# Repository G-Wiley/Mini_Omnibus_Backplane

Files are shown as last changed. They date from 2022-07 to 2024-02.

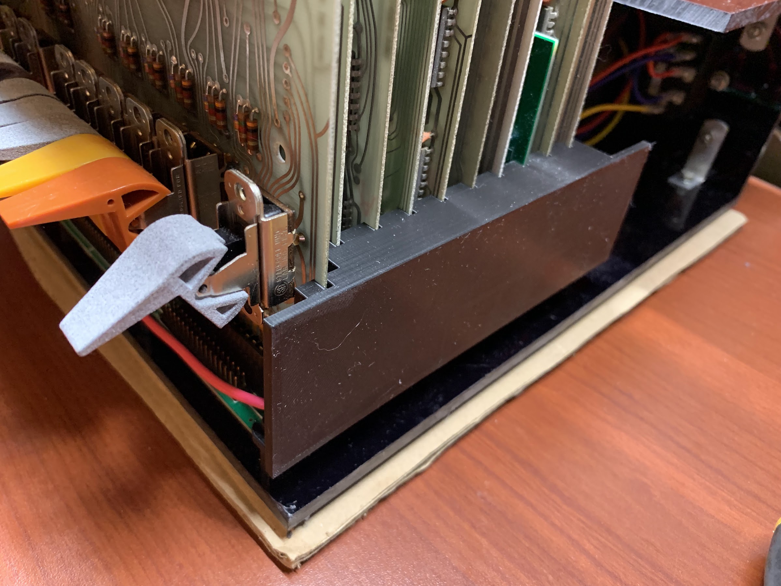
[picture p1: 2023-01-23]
Mini Backplane Card Guide photo.jpg

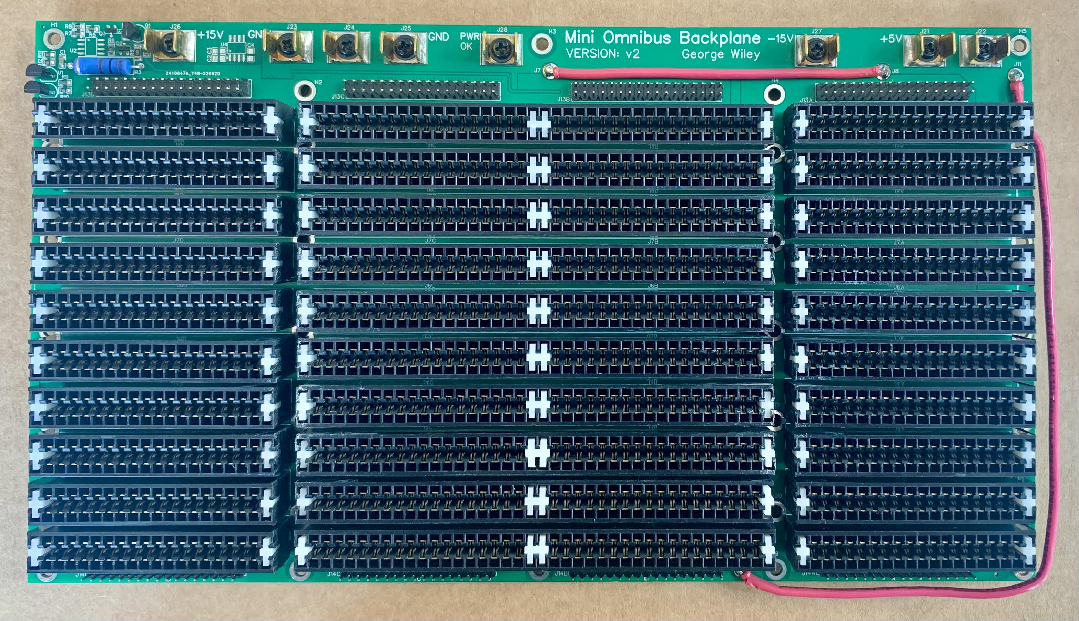
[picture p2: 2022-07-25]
Mini Omnibus Backplane v2 photo.jpg

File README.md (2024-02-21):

# Mini_Omnibus_Backplane
Small PDP-8/E/F/M Omnibus backplane for debugging Omnibus boards and to build a minimal system



For a long time I didn’t have a PDP-8/E/F/M chassis with backplane and power supply and wanted to get a system running using my Omnibus board collection. So, I built a small Omnibus backplane with only 8 slots which was sufficient to test basic stuff but not large enough to bring up OS/8. While debugging the first mini backplane I discovered some issues which have been fixed in version "v2". 

Through discussions in the Vintage Computer Forum and the PDP-8 group on Facebook there were a number of requests to release the design files of this mini backplane to use it for debugging and to build a system for those who do not have a real PDP-8 chassis+backplane+power supply. Included here are circuit board fabrication files, component source information and supplemental drawings and build documentation so people can build their own mini backplane.

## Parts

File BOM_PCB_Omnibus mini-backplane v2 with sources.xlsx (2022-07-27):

ID | Name | Designator | Footprint | Qty | Manufacturer Part | Manufacturer | Supplier | Supplier Part | Price | Ext Price | Supplier Link
1 | 1kΩ 1% | R10,R12 | R0805 | 2 | 0805W8F1001T5E | UNI-ROYAL(Uniroyal Elec) | LCSC | C17513 | 0.002 | 0.004 | https://jlcpcb.com/partdetail/18201-0805W8F1001T5E/C17513 | B
2 | 53.6Ω 1% | R11 | R0805 | 1 | 0805W8F536JT5E | UNI-ROYAL(Uniroyal Elec) | LCSC | C17744 | 0.003 | 0.003 | https://jlcpcb.com/partdetail/18432-0805W8F536JT5E/C17744 | E
3 | 2.0kΩ 1% | R9 | R0805 | 1 | 0805W8F2001T5E | UNI-ROYAL(Uniroyal Elec) | LCSC | C17604 | 0.003 | 0.003 | https://jlcpcb.com/partdetail/18292-0805W8F2001T5E/C17604 | B
4 | MC34164P-5G | U3,U1 | TO-92-3_L4.9-W3.7-P1.27-L | 2 | MC34164P-5G | ON Semi | Digikey | MC34164P-005GOS-ND | 0.88 | 1.76 | https://www.digikey.com/en/products/detail/onsemi/MC34164P-5G/919094
5 | 100nF | C1 | C0805 | 1 | CC0805KRX7R9BB104 | YAGEO | LCSC | C49678 | 0.004 | 0.004 | https://jlcpcb.com/partdetail/Yageo-CC0805KRX7R9BB104/C49678 | B
6 | 47kΩ | R7,R5 | R0805 | 2 | 0805W8F4702T5E | UNI-ROYAL(Uniroyal Elec) | LCSC | C17713 | 0.002 | 0.004 | https://jlcpcb.com/partdetail/18401-0805W8F4702T5E/C17713 | B
7 | 470kΩ | R8 | R0805 | 1 | 0805W8F4703T5E | UNI-ROYAL(Uniroyal Elec) | LCSC | C17709 | 0.004 | 0.004 | https://jlcpcb.com/partdetail/18397-0805W8F4703T5E/C17709 | B
8 | 100Ω | R3 | RES-TH_BD5.0-L15.5-P19.50-D0.70 | 1 | RSF2JT100R | Stackpole Electronics Inc | Digikey | RSF2JT100RTR-ND | 0.34 | 0.34 | https://www.digikey.com/en/products/detail/stackpole-electronics-inc/RSF2JT100R/1686318
9 | MMBT3904 | Q2 | SOT-23-3_L2.9-W1.3-P1.90-LS2.4-BR | 1 | MMBT3904 | Jiangsu Changjing Electronics Technology Co., Ltd. | LCSC | C20526 | 0.014 | 0.014 | https://jlcpcb.com/partdetail/21237-MMBT3904/C20526
10 | MMBT3906 | Q3 | SOT-23-3_L2.9-W1.3-P1.90-LS2.4-BR | 1 | MMBT3906 | ST(Semtech) | LCSC | C84105 | 0.01 | 0.01 | https://jlcpcb.com/partdetail/st_semtech-MMBT3906/C84105
11 | 100Ω | R1,R2 | R1206 | 2 | 1206W4F1000T5E | UNI-ROYAL(Uniroyal Elec) | LCSC | C17901 | 0.004 | 0.008 | https://jlcpcb.com/partdetail/18589-1206W4F1000T5E/C17901 | B
12 | 0Ω | R4 | R0805 | 1 | 0805W8F0000T5E | UNI-ROYAL(Uniroyal Elec) | LCSC | C17477 | 0.002 | 0.002 | https://jlcpcb.com/partdetail/18165-0805W8F0000T5E/C17477 | B
13 | 1.5kΩ | R6 | R0805 | 1 | 0805W8F1501T5E | UNI-ROYAL(Uniroyal Elec) | LCSC | C4310 | 0.002 | 0.002 | https://jlcpcb.com/partdetail/4717-0805W8F1501T5E/C4310 | B
14 | Keystone 1257 Quick-Fit | J21, J22, J23, J24, J25, J26, J27, J28 | KEYSTONE_1257_FP | 8 | 1257 | Keystone Electronics | Digikey | 36-1257-ND | 0.27 | 2.16 | https://www.digikey.com/en/products/detail/keystone-electronics/1257/211498
15 | X6521WR-2×17H-C30D60-gw-NSP | J14A, J14B, J14C, J14D, J13A, J13B, J13C, J13D | HDR-TH_34P-P2.54-H-M-R2-C17-S2.54-NO-SILK-PINS | 8 | PRPC017DAAN-RC | Sullins Connector Solutions | Digikey | S2011EC-17-ND | 0.671 | 5.368 | https://www.digikey.com/en/products/detail/sullins-connector-solutions/PRPC017DAAN-RC/2775277
16 | Omnibus | J1B-J1C, J2B-J2C, J3B-J3C, J4B-J4C, J5B-J5C, J6B-J6C, J7B-J7C, J8B-J8C, J9B-J9C, J10B-J10C | OMNIBUS CARD EDGE SOCKET | 10 | n/a | n/a | AliExpress alinsin store | 1PCS 2X40 80PIN | 2.91 | 29.1 | https://www.aliexpress.com/item/2255801094078491.html
16 | Omnibus | J1A & J1D, J2A & J2D, J3A & J3D, J4A & J4D, J5A & J5D, J6A & J6D, J7A & J7D, J8A & J8D, J9A & J9D, J10A & J10D | OMNIBUS CARD EDGE SOCKET | 10 | n/a | n/a | AliExpress alinsin store | 1PCS 2X43 86PIN | 3.1 | 31 | https://www.aliexpress.com/item/2255801094078491.html
17 | 2N3904BU | Q1 | TO-92-3_L5.1-W4.1-P1.27-L | 1 | 2N3904BU | ON Semi | Digikey | 2N3904FS-ND | 0.38 | 0.38 | https://www.digikey.com/en/products/detail/onsemi/2N3904BU/1413
 | PCB, Mini Backplane v2 | - | - | 1 |  | JLCPCB | JLCPCB |  |  |  | https://jlcpcb.com/
 | cap screw, M3, 8 mm | H1 - H30 | - | 30 |  |  | Amazon |  |  |  | https://www.amazon.com/dp/B07CMQ1SQH
 | cap screw, M3, 12 mm | - | - | 30 |  |  | Amazon |  |  |  | https://www.amazon.com/dp/B07CNFTK99
 | M3 split lock washer | - | - | 60 |  |  | Amazon |  |  |  | https://www.amazon.com/dp/B07Z2FJ2XW
 | M3 flat washer | - | - | 30 |  |  | Amazon |  |  |  | https://www.amazon.com/dp/B018TG7QGW
 | pan head screw, M3, 4 mm | - | - | 8 |  |  | Amazon |  |  |  | https://www.amazon.com/dp/B0748BR25Y
 | nut, M3, black | - | - | 8 |  |  | Amazon |  |  |  | https://www.amazon.com/dp/B01IWUSDYY
 | nylon spacer, threaded, M3 | - | - | 12 |  |  | Amazon |  |  |  | https://www.amazon.com/dp/B072LGMRVD
 | acrylic sheet, 1/4 inch | - | - | 1 | n/a | various | ePlastics | scrap |  |  | n/a

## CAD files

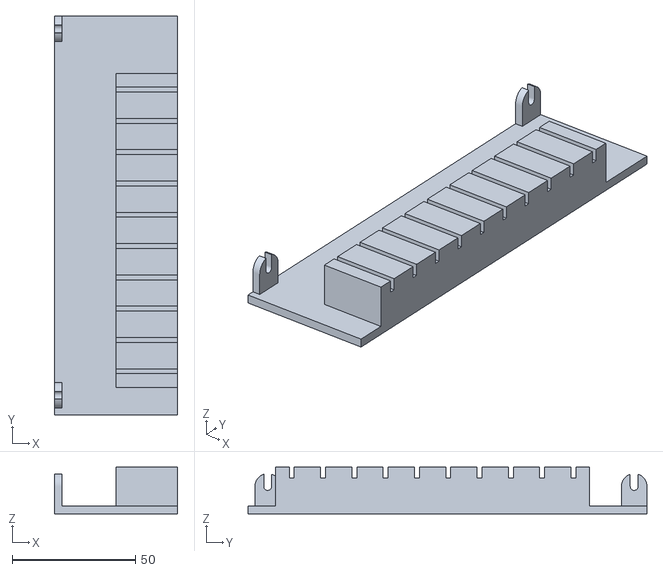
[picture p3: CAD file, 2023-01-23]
Mini Backplane Card Guide 10 same v00.stl
50.0 x 161.9 x 19.0

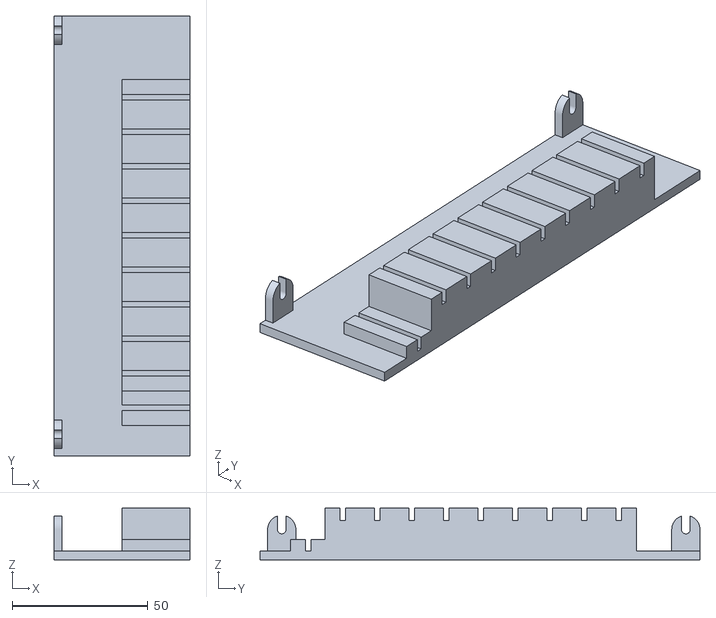
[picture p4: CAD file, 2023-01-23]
Mini Backplane Card Guide v00.stl
50.0 x 161.9 x 19.0

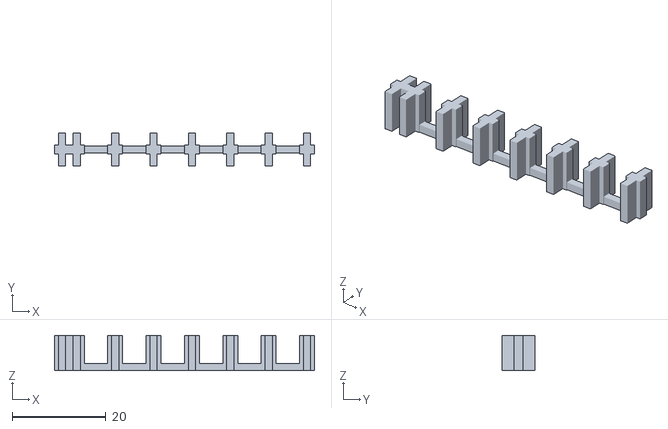
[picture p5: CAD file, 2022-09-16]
connector_shim_1_slot_v06.stl
55.4 x 7.01 x 7.51

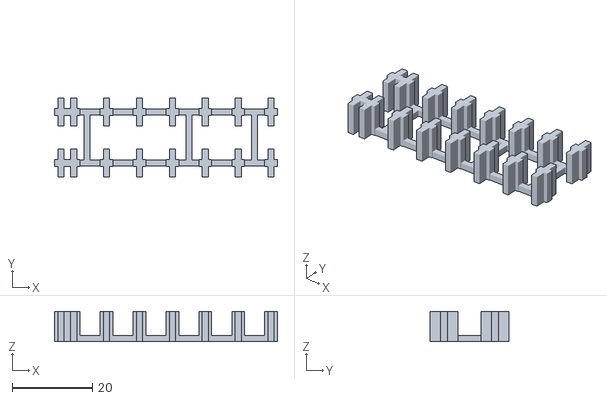
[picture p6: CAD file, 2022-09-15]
connector_shim_2_slot_v06.stl
55.4 x 19.7 x 7.51

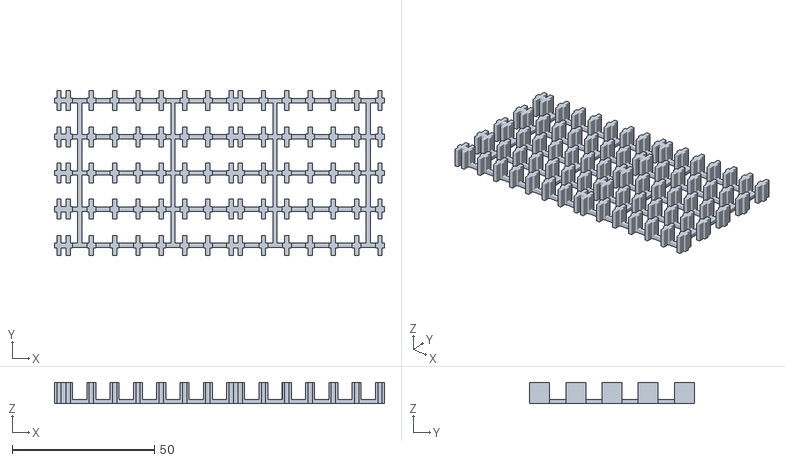
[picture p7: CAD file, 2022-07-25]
connector_shim_v06.stl
115.9 x 57.8 x 7.51

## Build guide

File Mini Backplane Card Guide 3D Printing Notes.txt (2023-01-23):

Mini Backplane Card Guide 3D Printing Notes

Set the Wall Thickness to 1.6 mm so the 3 mm thick side and feet will be solid and strong.

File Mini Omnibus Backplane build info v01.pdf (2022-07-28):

## Instructions to modify the edge connectors #1

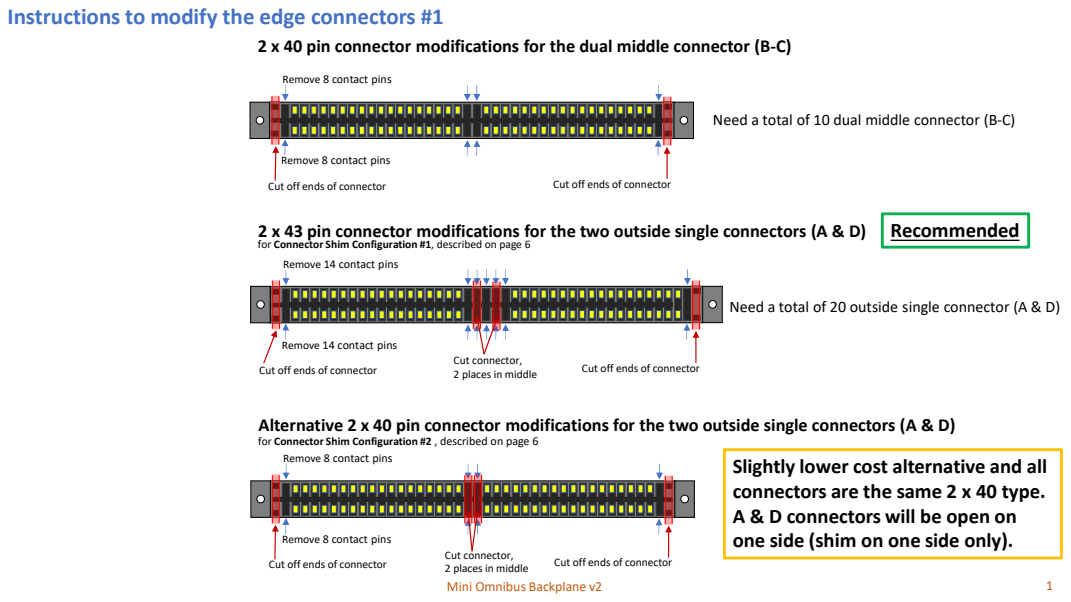
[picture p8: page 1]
Recommended; Mini Omnibus Backplane v2

2 x 40 pin connector modifications for the dual middle connector (B-C)

Remove 8 contact pins

Need a total of 10 dual middle connector (B-C)

Cut off ends of connector
2 x 43 pin connector modifications for the two outside single connectors (A & D)
for Connector Shim Configuration #1, described on page 6
Remove 14 contact pins

Need a total of 20 outside single connector (A & D)

Cut off ends of connector Cut connector,
2 places in middle

Alternative 2 x 40 pin connector modifications for the two outside single connectors (A & D)
for Connector Shim Configuration #2 , described on page 6

Slightly lower cost alternative and all
connectors are the same 2 x 40 type.
A & D connectors will be open on
one side (shim on one side only).

Remove the extra connector contact pins
Remove the extra connector contact pins before cutting. The contact pins to be removed are indicated by the blue arrows on the previous page.

An easy way to remove the pins is to place the connector slot-side down, pin-side up, on a flat surface that has an opening that allows the pins to be easily pushed through. The photo below shows an example of needle nose pliers gripping a contact pin which is pressed downward.

The example below shows two sides of a desk supporting the connector. A simple alternative would be to drill a large hole in a block of wood to support the connector while pushing the contact pin downward but to allow the removed pin to slip through the opening.

## Instructions to modify the edge connectors #2

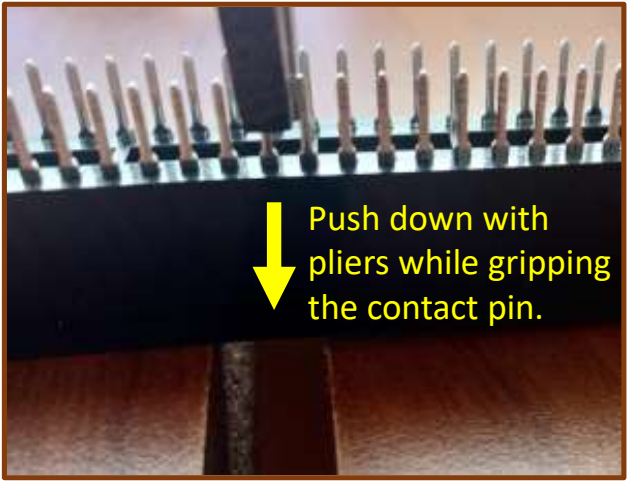
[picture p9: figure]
Push down with pliers while gripping the contact pin.

Mini Omnibus Backplane v2 | 2

Cutting the edge connectors
I used a small 7 ¼ inch power miter saw with a 140 tooth blade. Make the cuts at the locations indicated by the red bands on the first page.

The photo below shows a guide taped to the saw that is used to help align the connectors during the cutting process. Notice the icon in the lower left warning to not put your hand there, so a clamp is necessary to secure the connector while cutting. Small marks from the connector pins are visible on the paper guide. I didn't have the marks perfectly aligned when I attached the paper guide and adjusted the position of the connector early in the cutting process. The connector pins made the small dots to the right of the larger marks. The connectors were cut lying flat with the open slot toward the front and the pins pressed against the guide.

## Instructions to modify the edge connectors #3

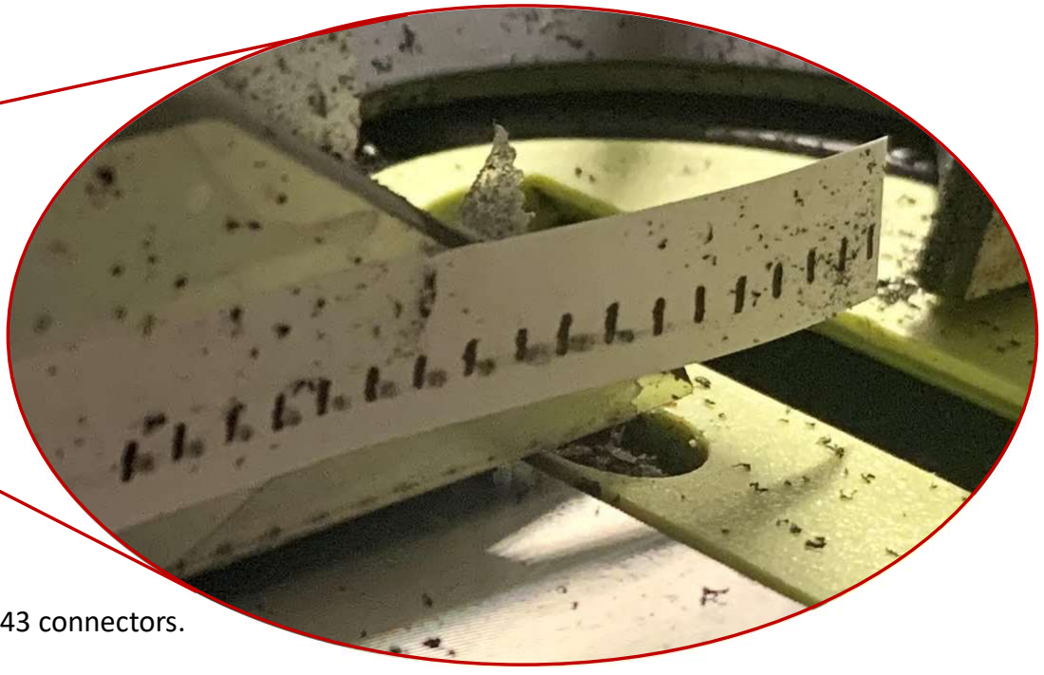
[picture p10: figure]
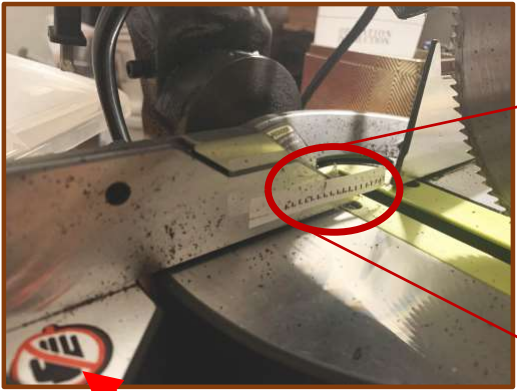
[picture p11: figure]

Begin the cutting process with ten 2 x 40 connectors and ten 2 x 43 connectors. Finish with ten B-C connectors and twenty A and D connectors.
Mini Omnibus Backplane v2 | 3

Mounting the Quick Fit terminals, Keystone Electronics 1257
Solder the Quick Fit terminals to the backplane first, before attaching any other components or connectors, because this requires a lot of heat and you’ll want to have easy access to the terminals from all sides during the hot air reflow soldering process. This also reduces the risk of overheating any other components that you’ll attach in subsequent steps.

The Quick Fit terminals should be secured to the backplane before soldering so the terminals don’t move while they are being soldered. A short M3 screw and nut are a good choice because they have a relatively small thermal mass. Below left is an image of the Quick Fit terminal attached to the backplane and below center is an image of the bottom side of the Quick Fit terminal. Notice that the bottom of the terminal has a small “Anti Rotation Tab” which will create a small gap between the base of the Quick Fit terminal and the metal pad on the PCB. This gap will allow solder to wick between the tab and the PCB pad.

I used a hot air reflow soldering tool with a 7 mm diameter nozzle to direct the heat to one side of the terminal at a time. Reflow air temperature was set to 340° C. I used Lead Free Solder Sn 99 Ag 0.3 Cu 0.7. Heat the entire side of the terminal first and then direct the heat toward the bottom of the terminal and the PCB pad on the side that you’re soldering and feed a generous amount of solder between the terminal and PCB pad. Keep the heat directed there until the solder flows and wicks well onto both surfaces. Repeat this for all four sides of the Quick Fit terminal. A photo of the soldered terminal is also shown below right.

## Mounting and Soldering the Quick Fit power terminals

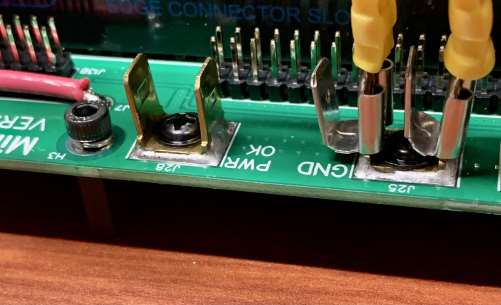
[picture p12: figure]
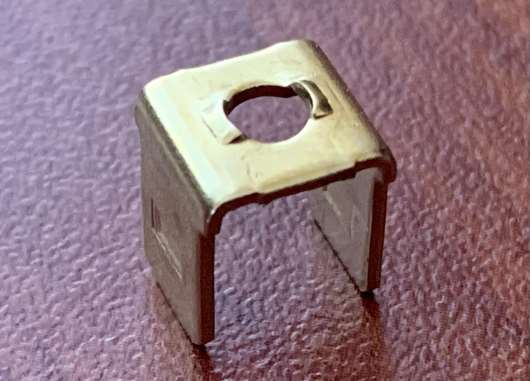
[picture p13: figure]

Mini Omnibus Backplane v2 | 4

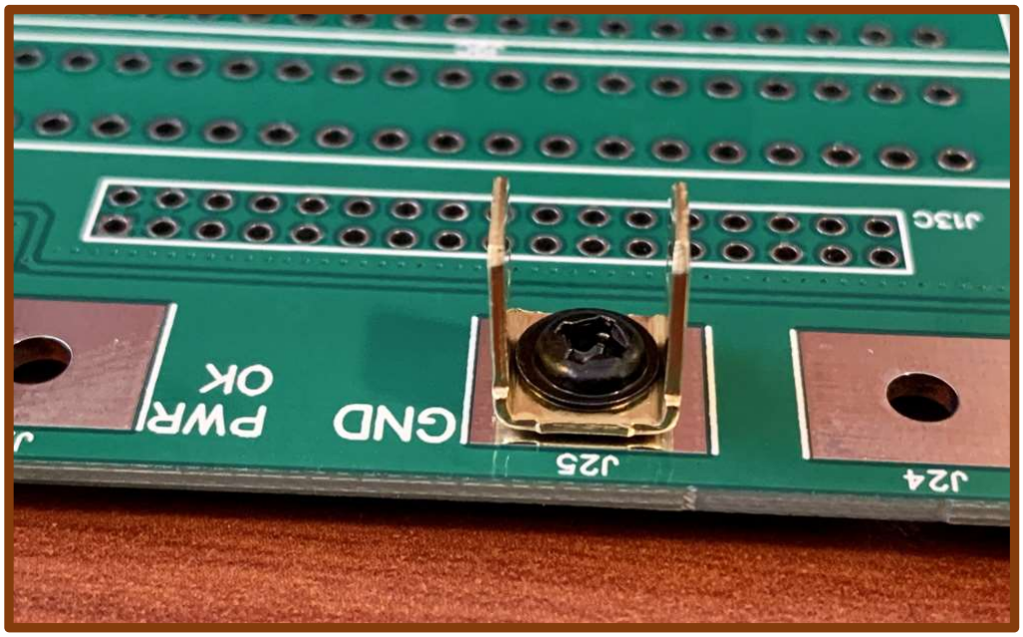
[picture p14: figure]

The PCB itself
The Mini Omnibus Backplane v2 was designed to be fabricated on the most basic PCB process. Voltage drops of power traces were analyzed based on the use of 1 ounce copper. The backplane can be fabricated from standard 1.6 mm thick FR4 material or a different thickness can be used without any adverse effects. The Lead Free HASL-RoHS process is recommended. The set of Gerber files are in “Gerber_PCB_Omnibus mini-backplane v2d.zip”. (At JLCPCB, simply upload the zip file, choose “LeadFree HASL-RoHS” process , and proceed to the SMT assembly section.)

## Ordering the PCB with SMT Assembly

SMT Assembly of the POWER OK circuit
The POWER OK circuit consists of a small group of SMT components in the upper left corner of the board. It is probably more convenient to order SMT assembly for these parts at the same time the PCB is ordered. JLCPCB offers a very cost-effective SMT assembly service, but it helps to know how to use it effectively. JLCPCB has two classifications of parts: “Basic Part” and “Extended Part”. Basic Parts are frequently used by many customers and are already loaded on carriers that can be configured easily. There’s no extra charge for Basic Parts, other than the component cost. Extended Parts are less often used and there’s an extra charge of a few dollars for the first instance of each Extended Part. The Mini Omnibus Backplane v2 is designed to use all Basic Parts to minimize cost. There are actually some non-Basic Parts in the design but these are through-hole parts that you will install after receiving the PCB with SMT from JLCPCB.

After uploading the PCB Gerber files in “The PCB itself” section above, just upload the following two files:

### 1. add the BOM file: “BOM_PCB_Omnibus mini-backplane v2_2022-06-19d SMT only.csv” 2. add the CPL file: “PickAndPlace_PCB_Omnibus mini-backplane v2_2022-06-19d.csv”

It is of course possible to order only the PCB but having JLCPCB also do the SMT assembly is very inexpensive and will save you a lot of time. Ballpark figure for PCB fabrication of 5 PCBs on Lead Free HASL-RoHS and 1.6 mm material is about $17. SMT assembly including parts cost for 5 boards is about $24. Be sure to claim one of the SMT assembly coupons that JLC frequently offers. I think the $24 SMT charge was discounted by $9, so I actually paid about $15 for SMT assembly (including parts cost).

Note that shipping from China to the US can add an additional 20% to 100% depending on the shipping speed that you require. Even with shipping, the total cost is quite painless.

Mini Omnibus Backplane v2 | 5

## Connector Shims #1

### Recommended

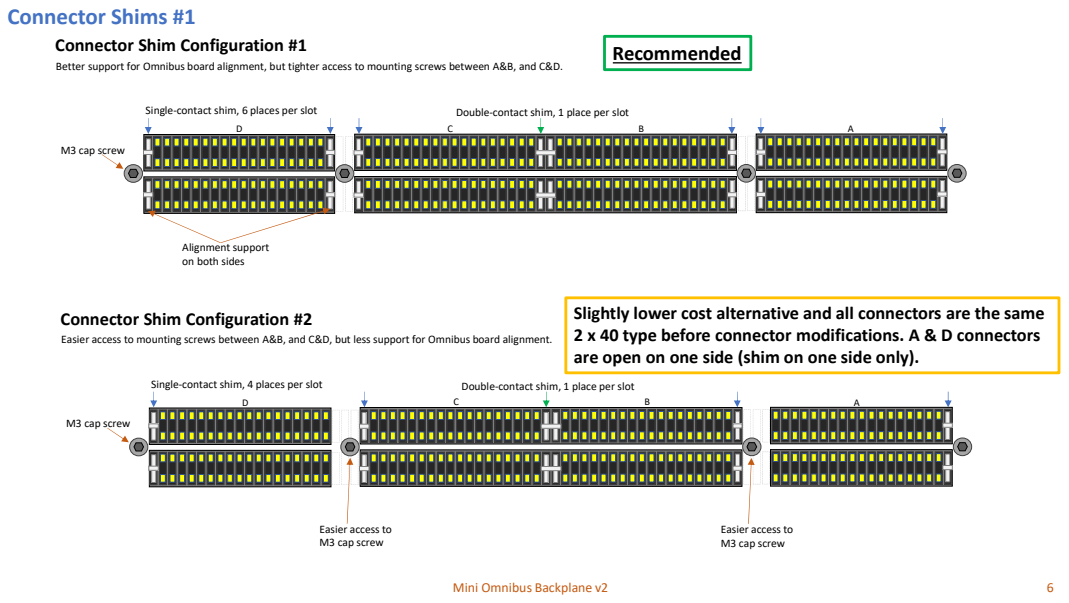
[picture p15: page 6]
Single-contact shim, 6 places per slot; Double-contact shim, 1 place per slot; M3 cap screw; Single-contact shim, 4 places per slot; Mini Omnibus Backplane v2

Connector Shim Configuration #1
Better support for Omnibus board alignment, but tighter access to mounting screws between A&B, and C&D.

Alignment support
on both sides

Connector Shim Configuration #2
Easier access to mounting screws between A&B, and C&D, but less support for Omnibus board alignment.

Slightly lower cost alternative and all connectors are the same
2 x 40 type before connector modifications. A & D connectors
are open on one side (shim on one side only).

Easier access to
M3 cap screw

The connector shims are 3D printed in a rack that contains exactly the number of shims required for a 10-slot backplane. There are 60 single-shims and 10 double-shims. An entire set of shims are printed together because this is easier to handle a single 3D print job and it reduces the printing cost.
The shims in the photo below were printed at JLCPCB in LEDO 6060 Resin. The file to be printed is “connector_shim_v06.stl”, an STL format file in millimeter units. (At JLCPCB, simply upload the file, choose “LEDO 6060 Resin”, and order the part.)

A network of 1 mm disposable ribs connects the entire set of shims. They can be cut apart easily using a set of diagonal cutters that is flat on one side. When separating a single shim, place the flat side of the diagonal cutter next to the part you are removing from the rib.

The single shims will probably fit rather loosely in the connector and should be glued so they remain in place. A tiny sub-drop of epoxy should hold the shim in place. Be very careful not to get any glue on the connector contacts.

## Connector Shims #2

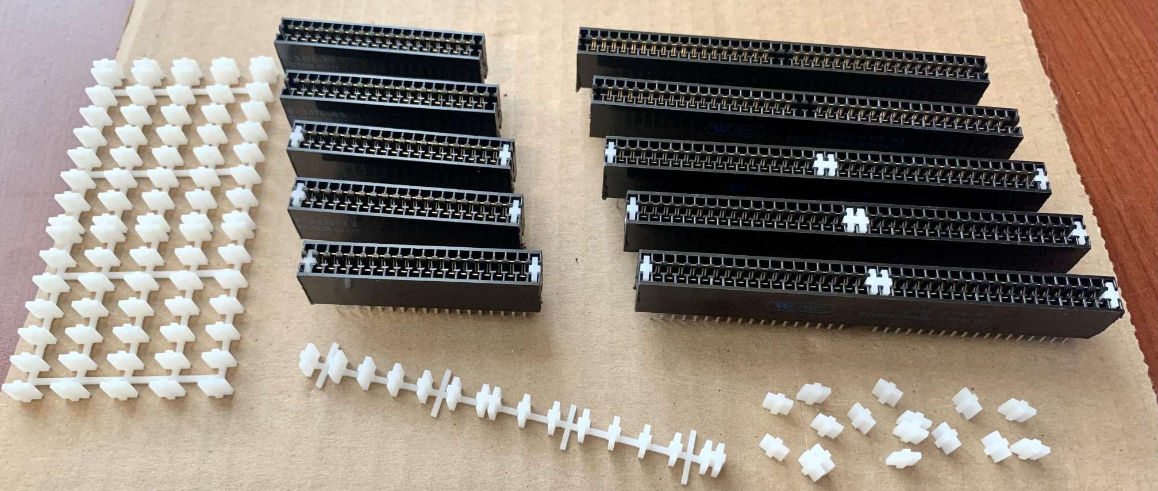
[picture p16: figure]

Mini Omnibus Backplane v2 | 7

Generally, install the shortest components first and the tallest go last.
1. The exception is to solder the Quick Fit terminals first because this requires a lot of heat and easy access to the terminals to apply heat and solder.
2. Next are the 2 watt resistor (R3), the transistor (Q1), and the MC34164 undervoltage sensors. Tne SMT components are already installed.
3. Next are the 34-pin headers: J13A, J13B, J13C, J13D, J14A, J14B, J14C, J14D.
4. Next are the edge connectors. Solder one terminal from each end first. Make certain the connector is aligned perfectly and reflow the joint at either end of both if a slight correction is necessary. When you’re certain that all connectors are aligned correctly, then solder the remaining connector pins.
5. Last are the two AWG 14 jumper wires. The short wire between J7 and J8 could be installed at any time but the longer wire between J11 and J12 will get in the way if it’s attached early in the assembly process. I made the longer wire long enough so I could easily access the screw heads along the right and bottom edges of the backplane.

## Order of Assembly

Mini Omnibus Backplane v2 | 8

#1

#4

#3

#2

#5

## Complete Assembly, not yet mounted

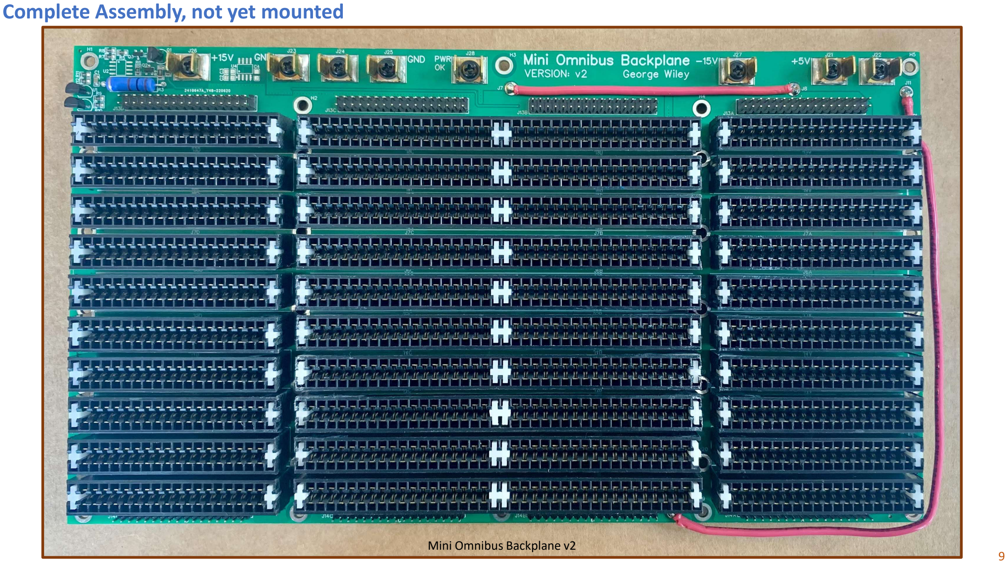
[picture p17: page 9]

Mini Omnibus Backplane v2
9

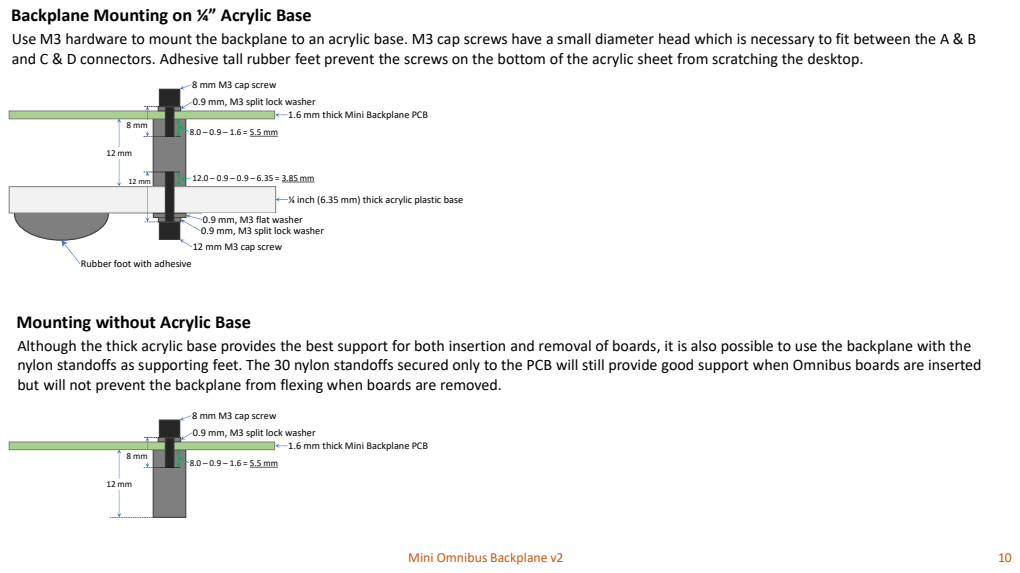
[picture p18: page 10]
Mini Omnibus Backplane v2

Backplane Mounting on ¼” Acrylic Base
Use M3 hardware to mount the backplane to an acrylic base. M3 cap screws have a small diameter head which is necessary to fit between the A & B
and C & D connectors. Adhesive tall rubber feet prevent the screws on the bottom of the acrylic sheet from scratching the desktop.

8 mm M3 cap screw

0.9 mm, M3 split lock washer 8 mm

1.6 mm thick Mini Backplane PCB

¼ inch (6.35 mm) thick acrylic plastic base ⁸.0 – 0.9 – 1.6 = 5.5 mm

0.9 mm, M3 flat washer
0.9 mm, M3 split lock washer
12 mm M3 cap screw

Rubber foot with adhesive

Mounting without Acrylic Base
Although the thick acrylic base provides the best support for both insertion and removal of boards, it is also possible to use the backplane with the
nylon standoffs as supporting feet. The 30 nylon standoffs secured only to the PCB will still provide good support when Omnibus boards are inserted
but will not prevent the backplane from flexing when boards are removed.

Single 10 Slot Backplane
Can be the backplane of a simple minimal 10-slot Omnibus system. The J13 and J14 headers can be used to connect a logic analyzer for debugging. The POWER OK signal can be driven from the on-board circuit (be sure that zero-ohm SMT jumper R4 is installed) or POWER OK can be driven from an external source and connected via J28 (be sure that zero-ohm SMT jumper R4 is removed). POWER OK should be driven from only a single source, either on-board or off-board.

## Using the Backplane

Double Backplane, 20 Omnibus slots, or 10 x n slots
It’s possible to cascade two mini backplanes to form a 20-slot system by installing four short 34-pin flat cables with IDC connectors between the J13 connectors of the front backplane and the J14 connectors of the rear backplane. The J13 and J14 connectors do not carry power so it is necessary to also make robust connections between the Quick Fit terminals J21 through J27 of the two backplanes. In theory it is possible to cascade more than two backplanes to form larger systems that have multiples of ten slots. This has not been tested or analyzed in detail.

The POWER OK signal can be driven from the on-board circuit of only one backplane in the cascaded configuration. Be sure that the zero-ohm SMT jumper R4 is installed in that backplane and removed in the other backplanes in this configuration because POWER OK should be driven from only a single source. POWER OK can be also driven from an external source and connected via J28 of any of the backplanes in the cascaded configuration (be sure that zero-ohm SMT jumper R4 is removed from all backplanes). The POWER OK signal is connected through the J13 and J14 flat cables so that a single POWER OK signal is connected to all slots in a system having cascaded backplanes.
Replacement for a bad Omnibus Backplane
Although the dimensions of the Mini Omnibus Backplane are not identical to a real DEC Omnibus backplane, it is intended that the Mini Omnibus Backplane be able to be a substitute for a bad backplane. An Omnibus Bridge v2 PCB has been designed to connect to the J13 or J14 headers and plug into to the good backplane in a system being repaired. Four Omnibus Bridge v2 PCBs and short 34-pin cables are required. In this situation the POWER OK signal is most likely driven by a circuit in the power supply of the system being repaired so be sure that the zero-ohm SMT jumper R4 is removed from the Mini Omnibus Backplane.
Mini Omnibus Backplane v2 | 11

## Backplane Configurations

### Side View

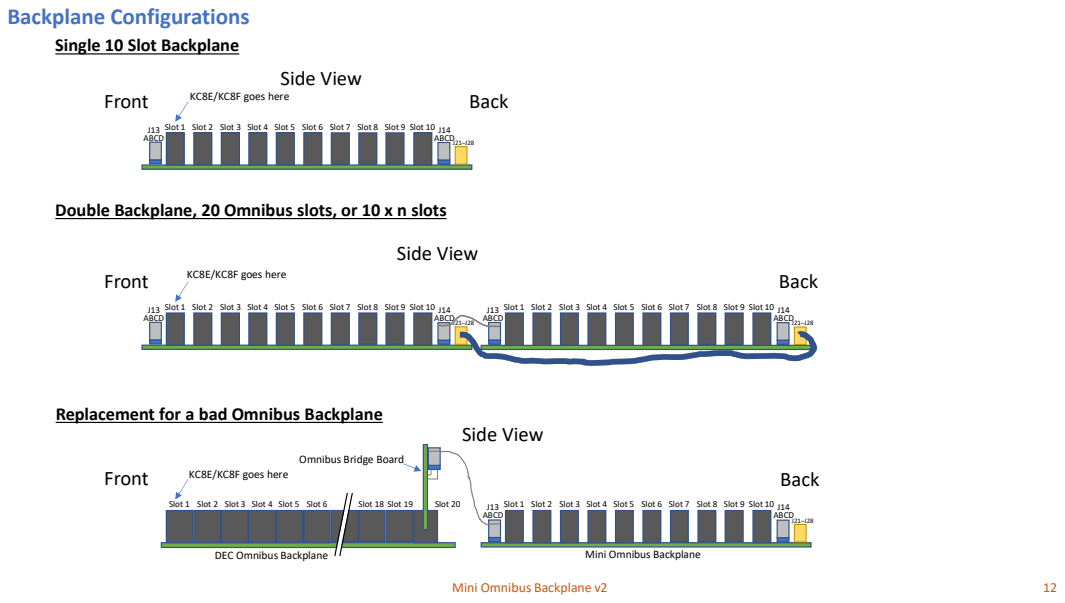
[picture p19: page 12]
Mini Omnibus Backplane v2; Front; Back KC8E/KC8F goes here; J14 ABCD; Side View; Slot 1 Slot 2 Slot 3 Slot 4 Slot 5 Slot 6; Slot 18 Slot 19; Slot 20; J13 ABCD; J21–J28 KC8E/KC8F goes here; DEC Omnibus Backplane; Mini Omnibus Backplane; Back

Single 10 Slot Backplane

Slot 1 Slot 2 Slot 3 Slot 4 Slot 5 Slot 6 Slot 7 Slot 8 Slot 9 Slot 10
J13 ABCD

Double Backplane, 20 Omnibus slots, or 10 x n slots

Replacement for a bad Omnibus Backplane

Omnibus Bridge Board

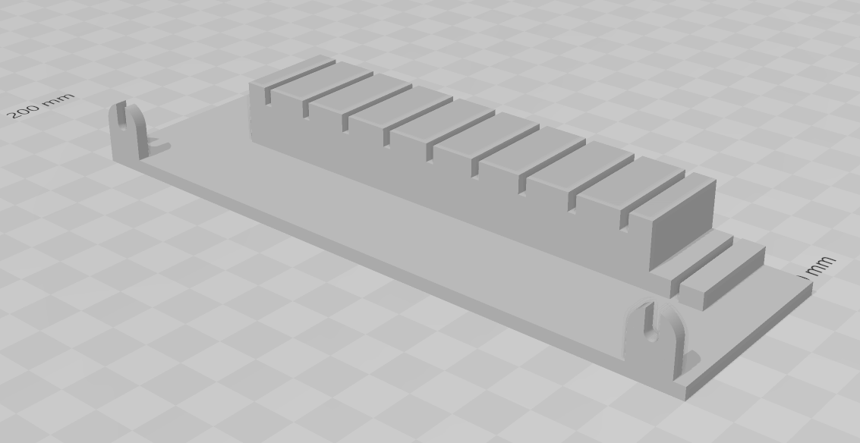
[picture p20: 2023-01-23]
Mini Backplane Card Guide rendering.png

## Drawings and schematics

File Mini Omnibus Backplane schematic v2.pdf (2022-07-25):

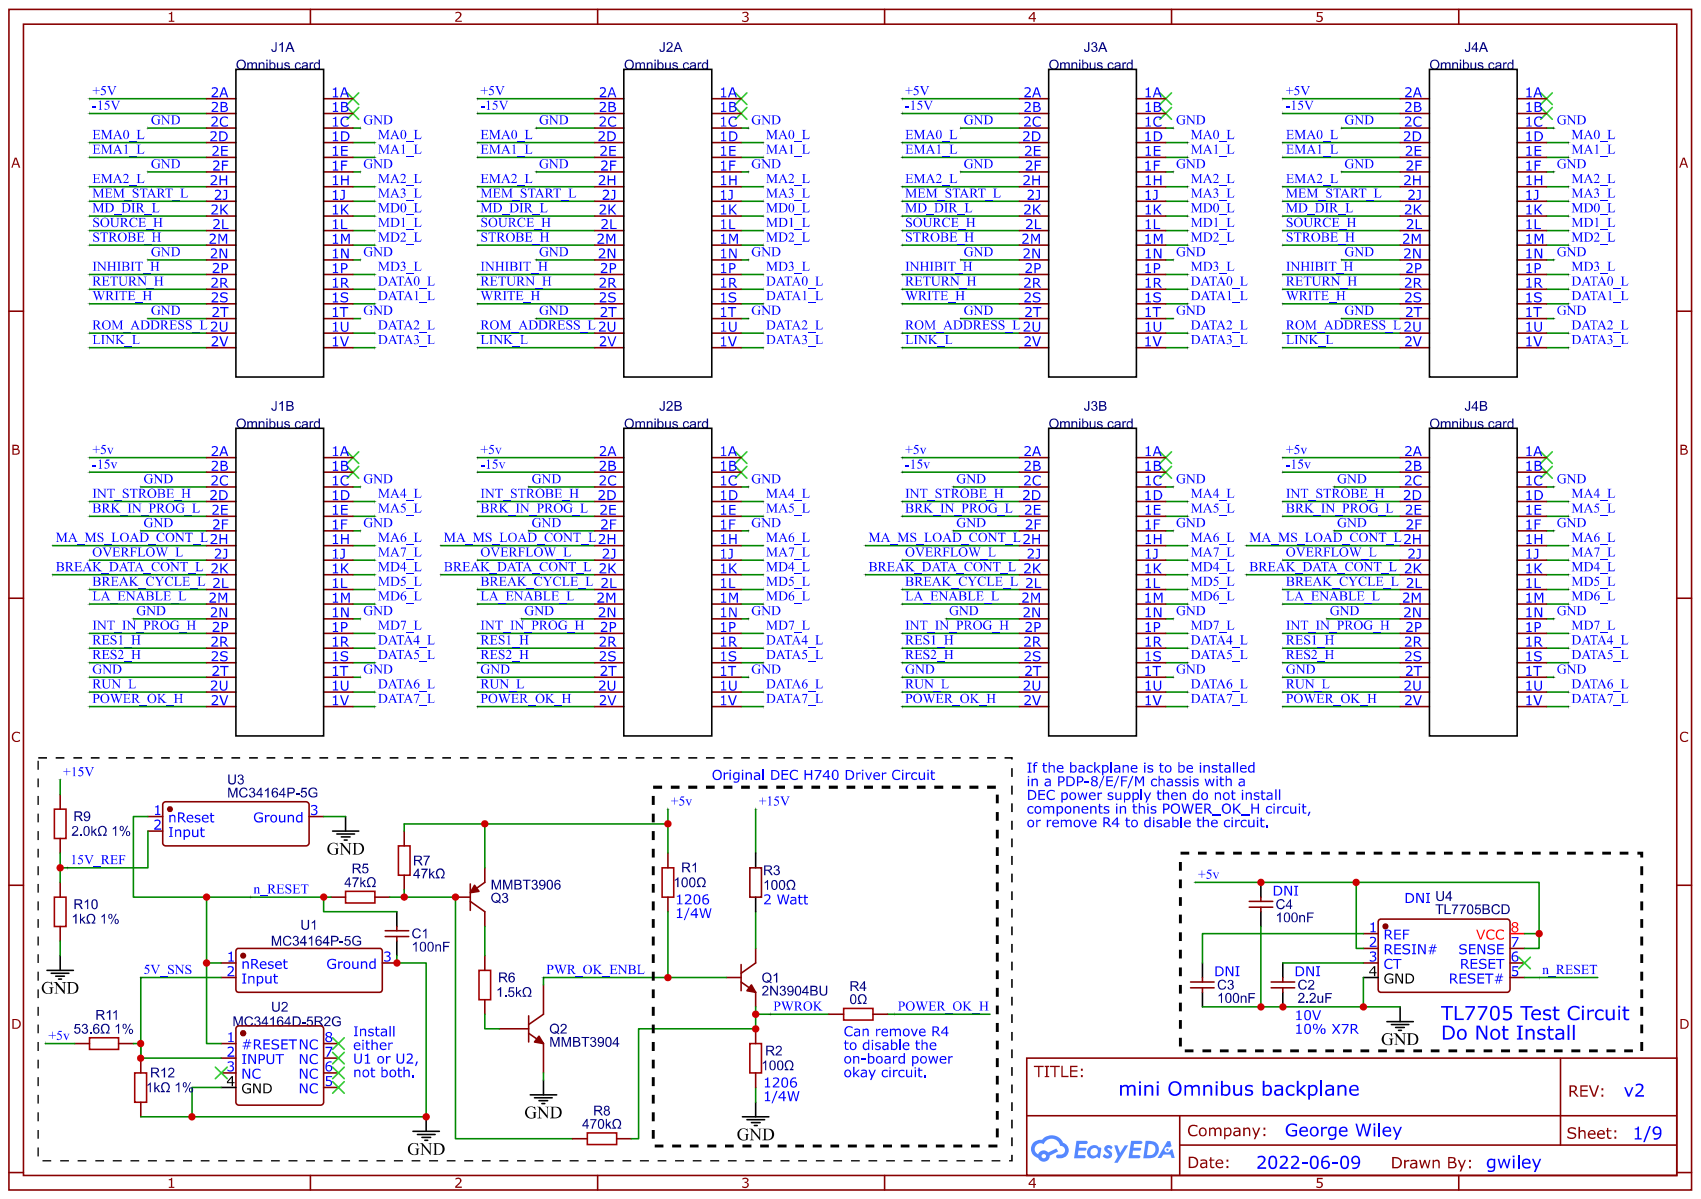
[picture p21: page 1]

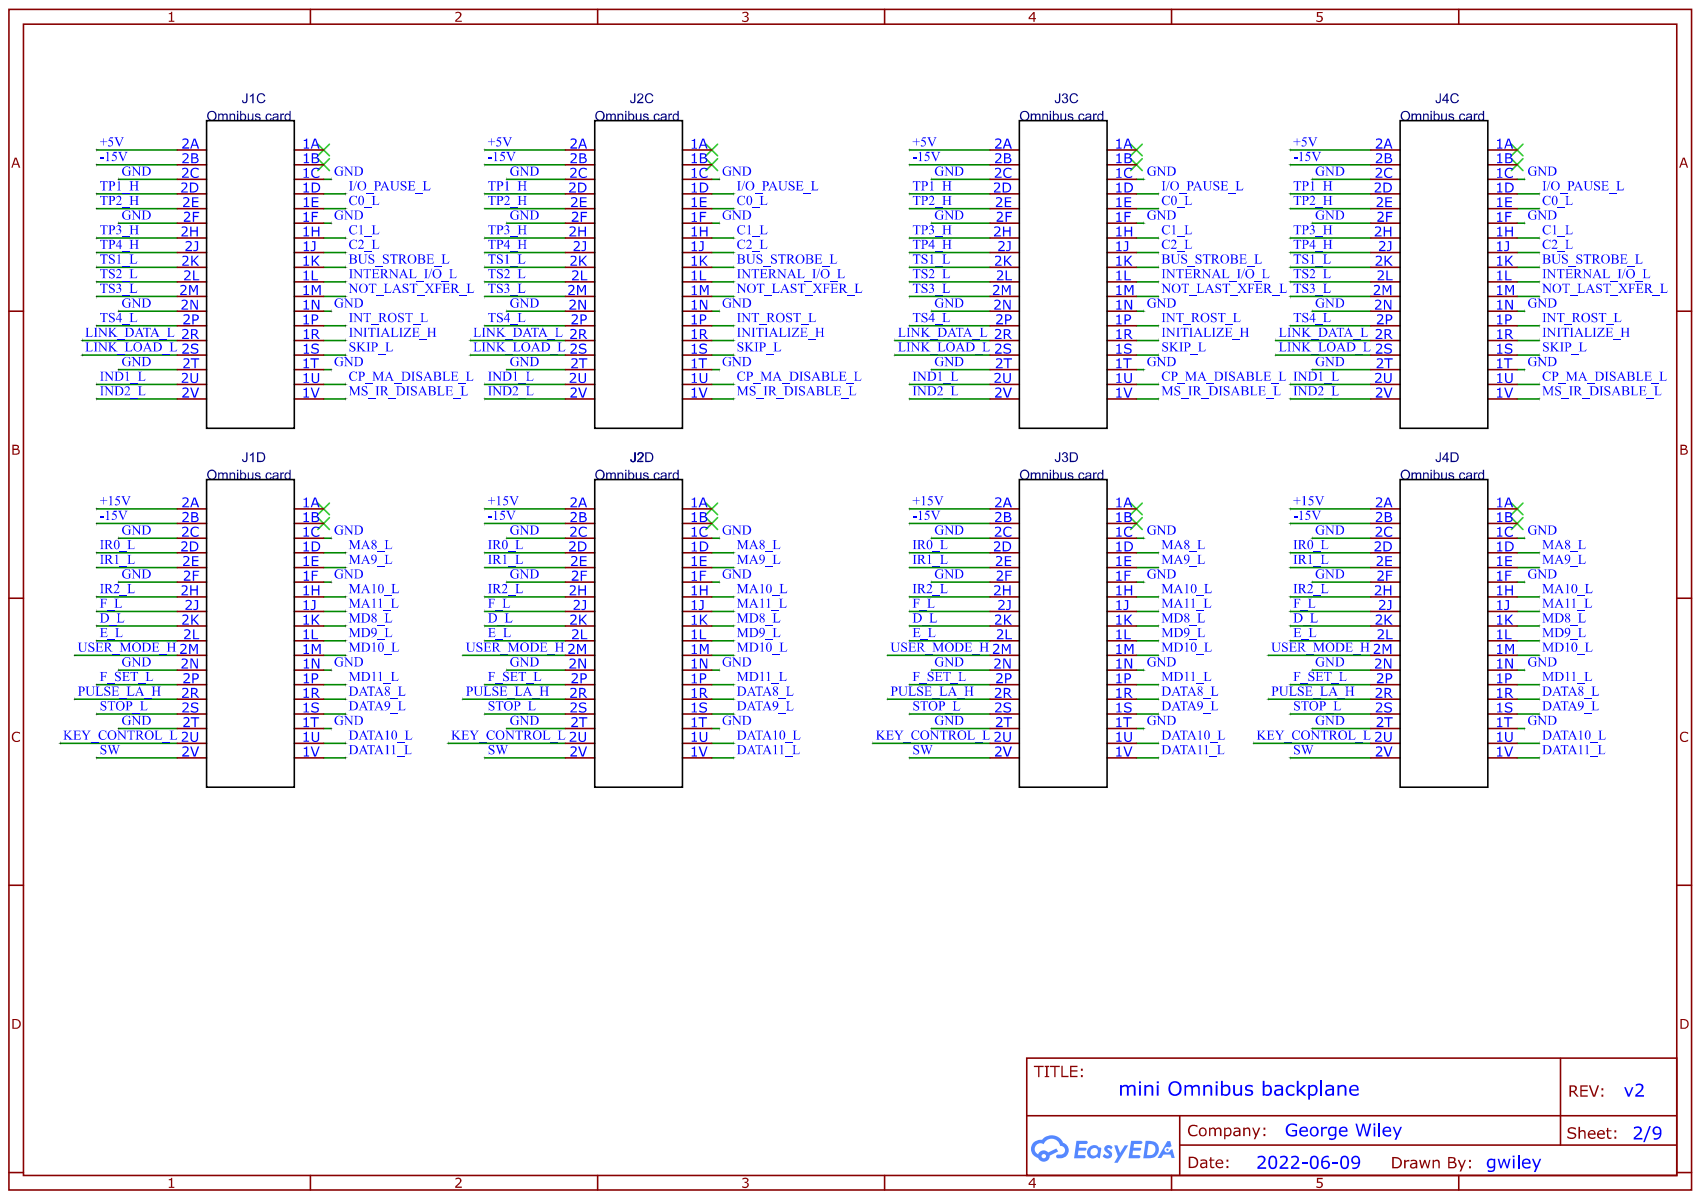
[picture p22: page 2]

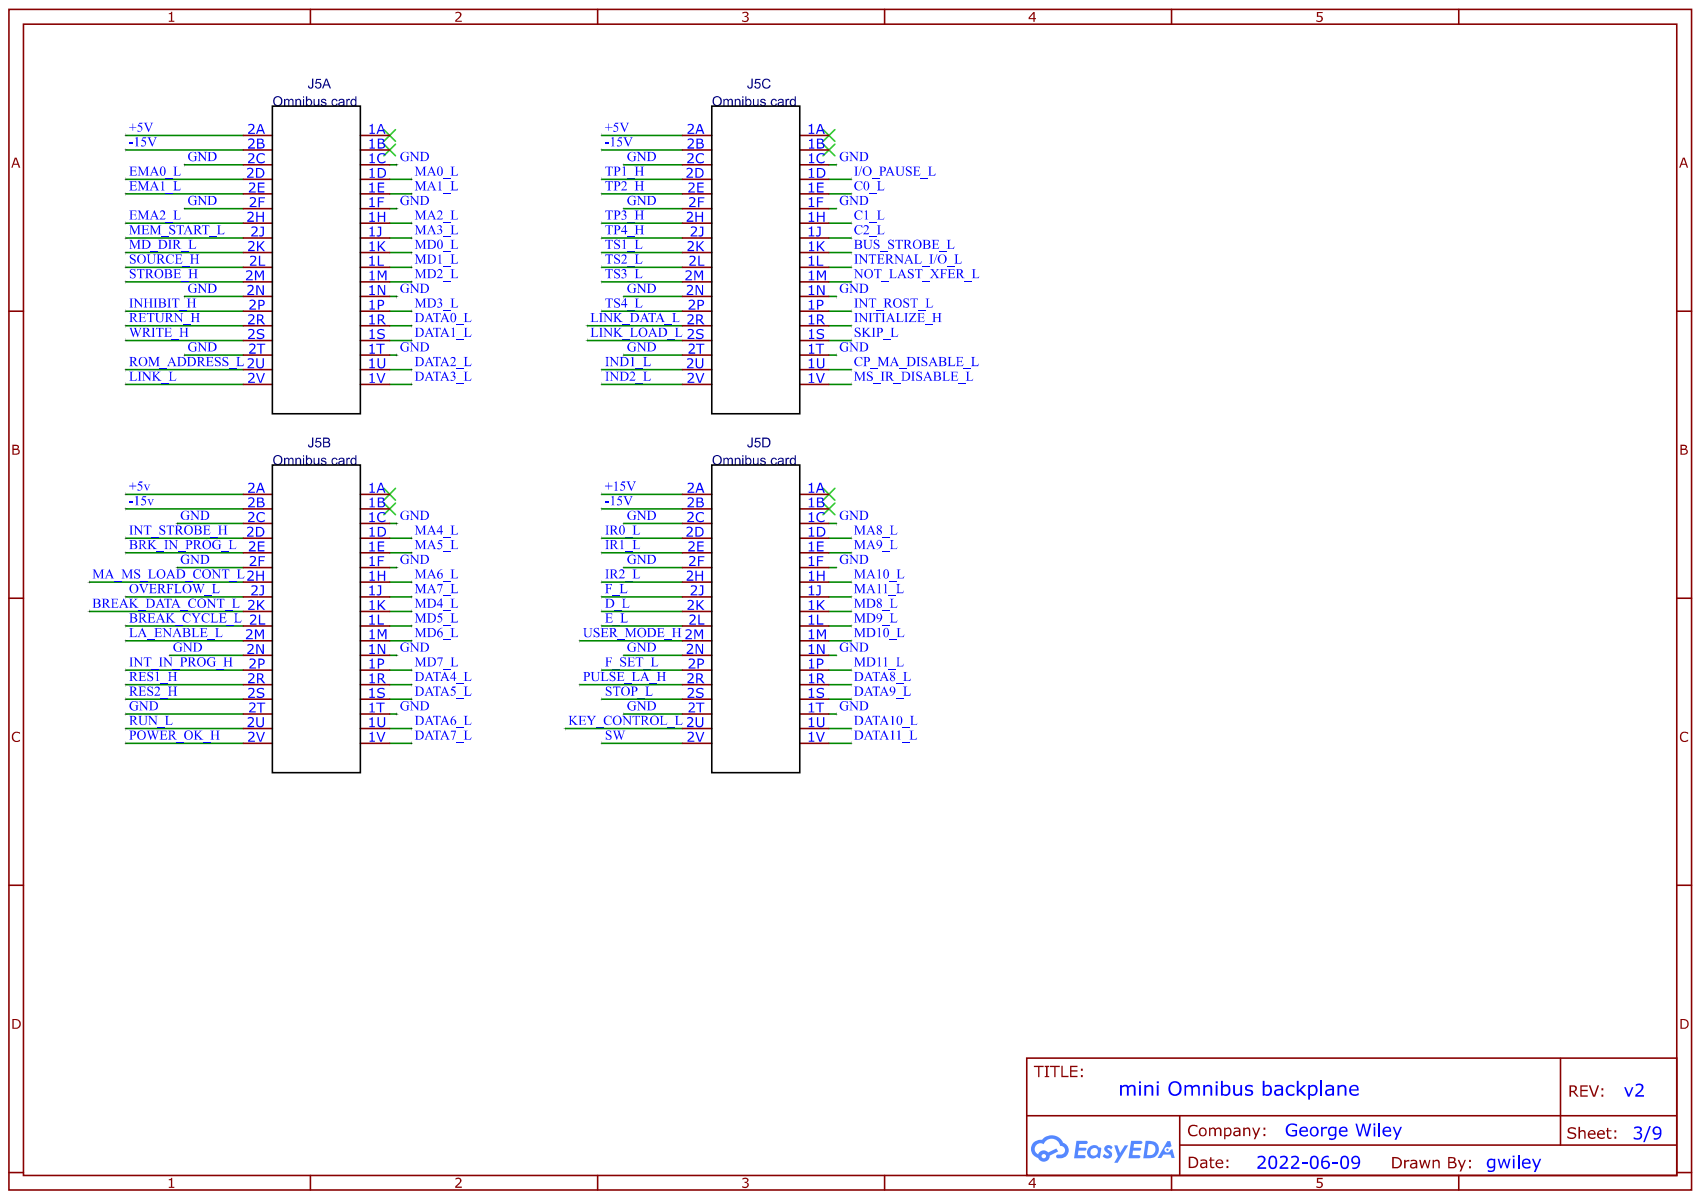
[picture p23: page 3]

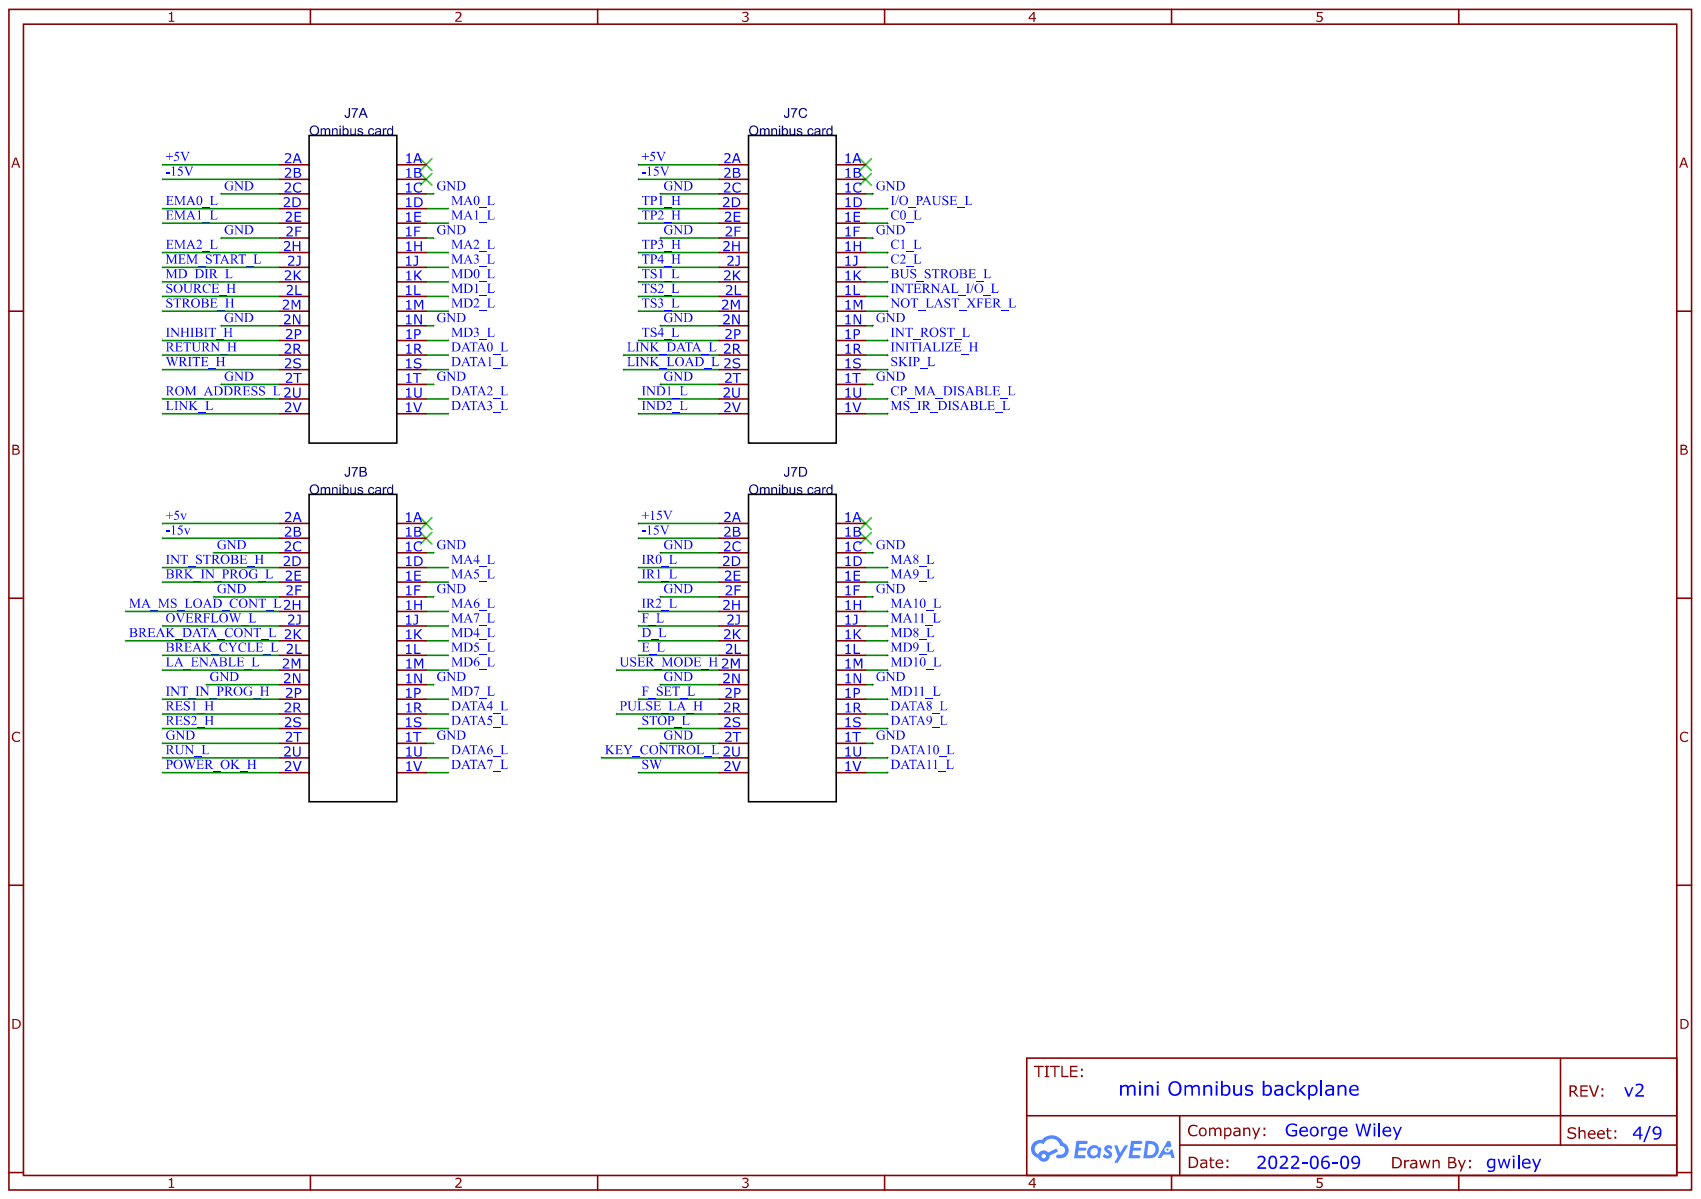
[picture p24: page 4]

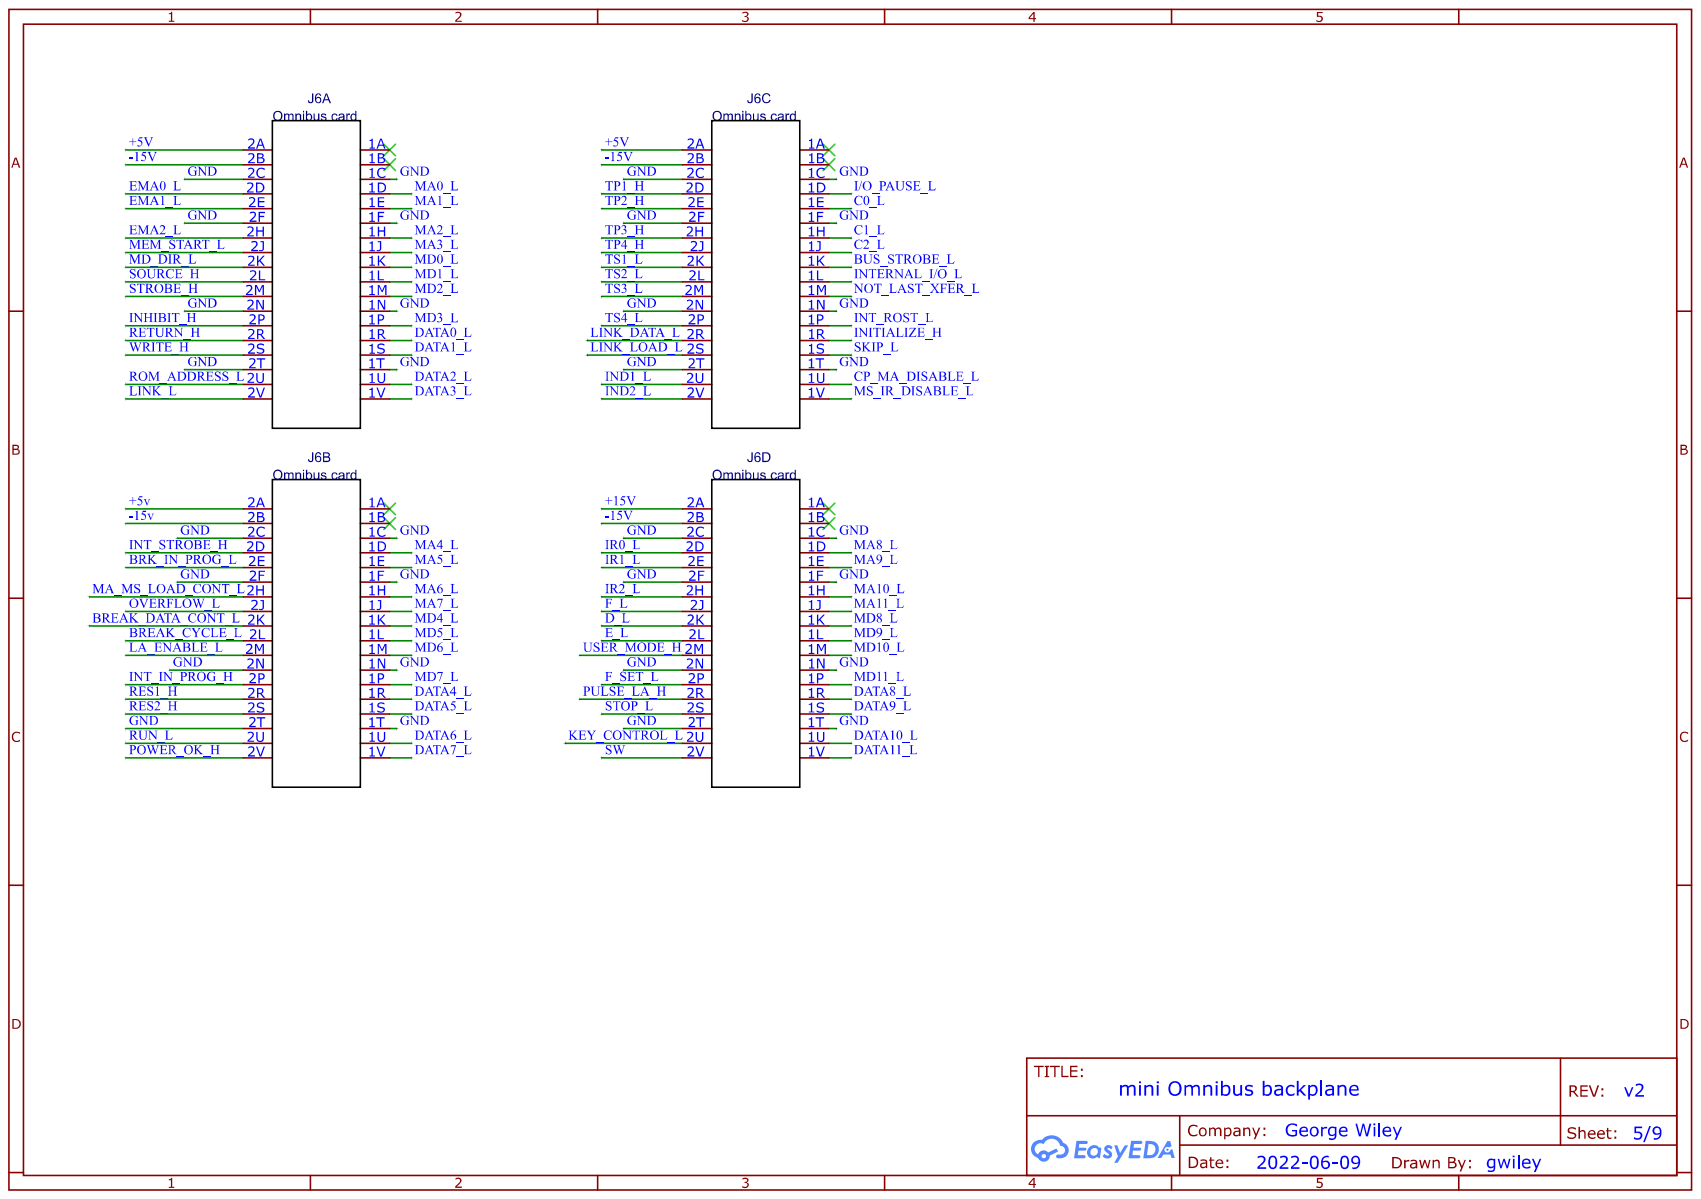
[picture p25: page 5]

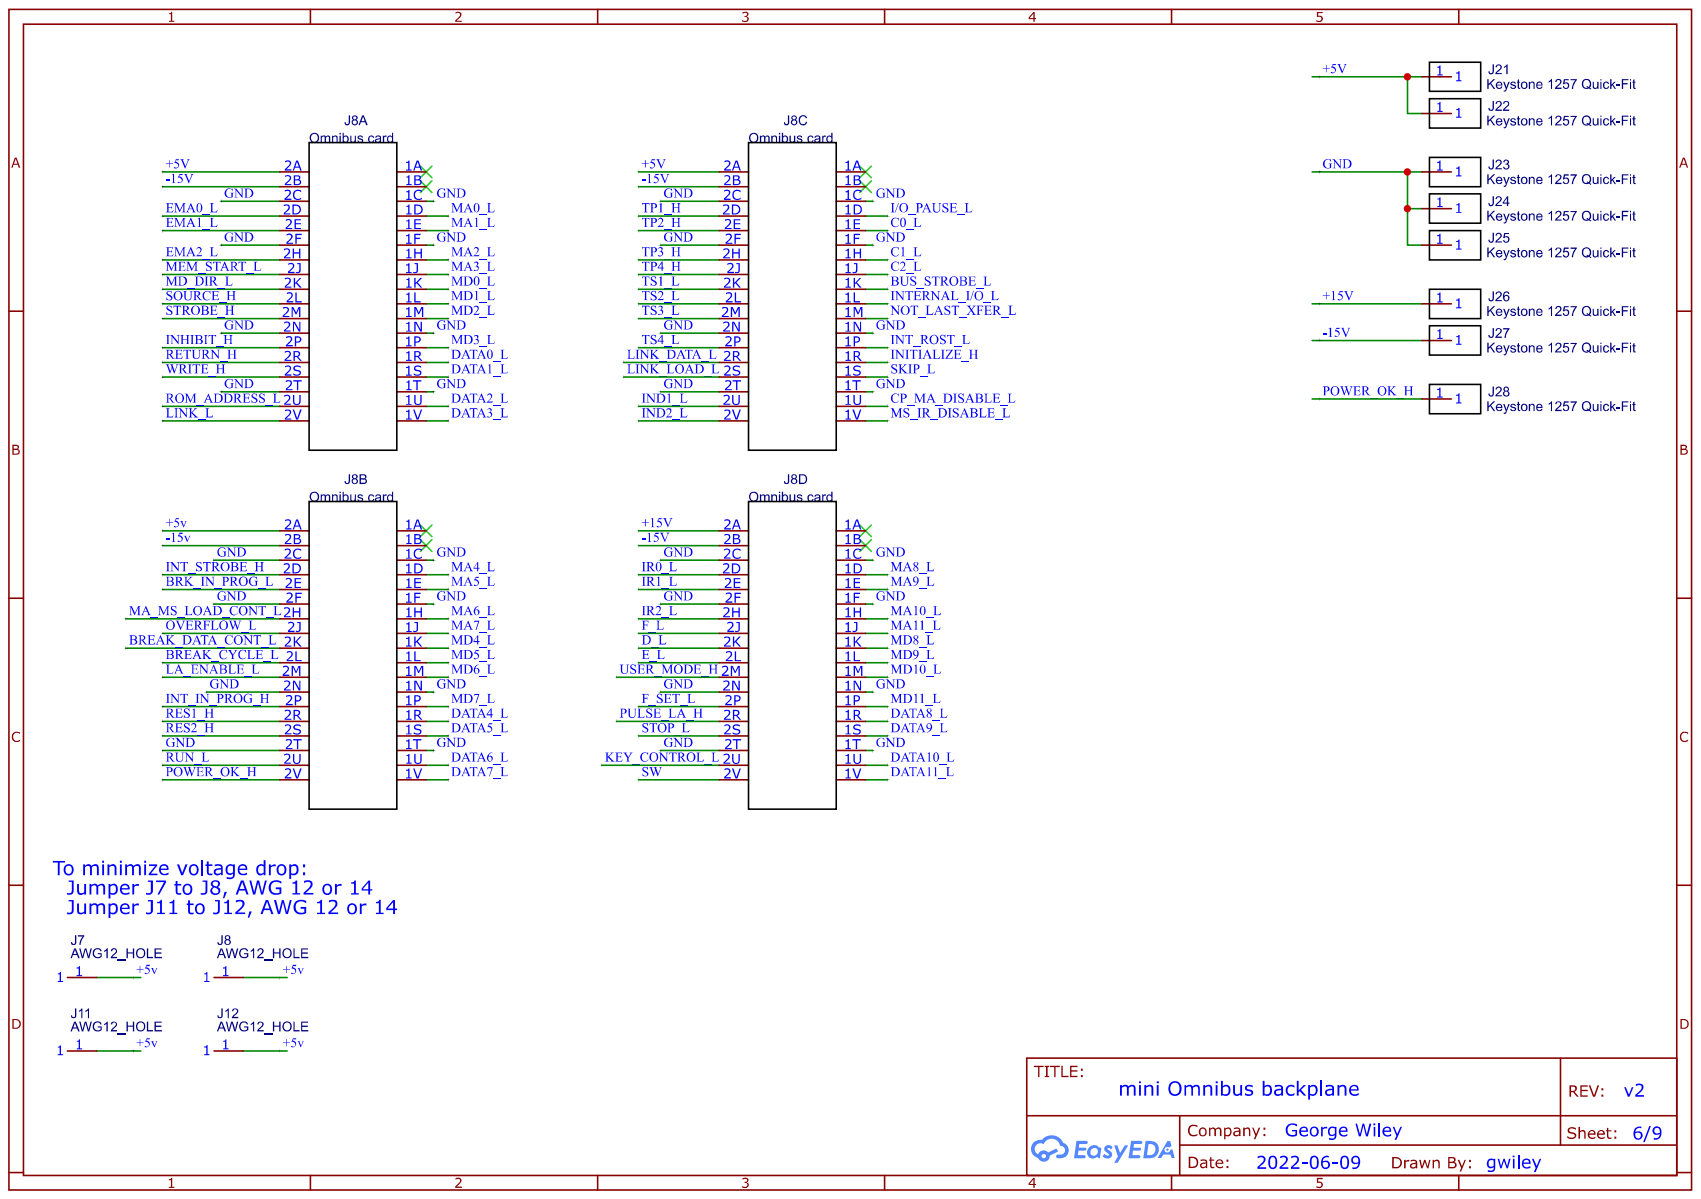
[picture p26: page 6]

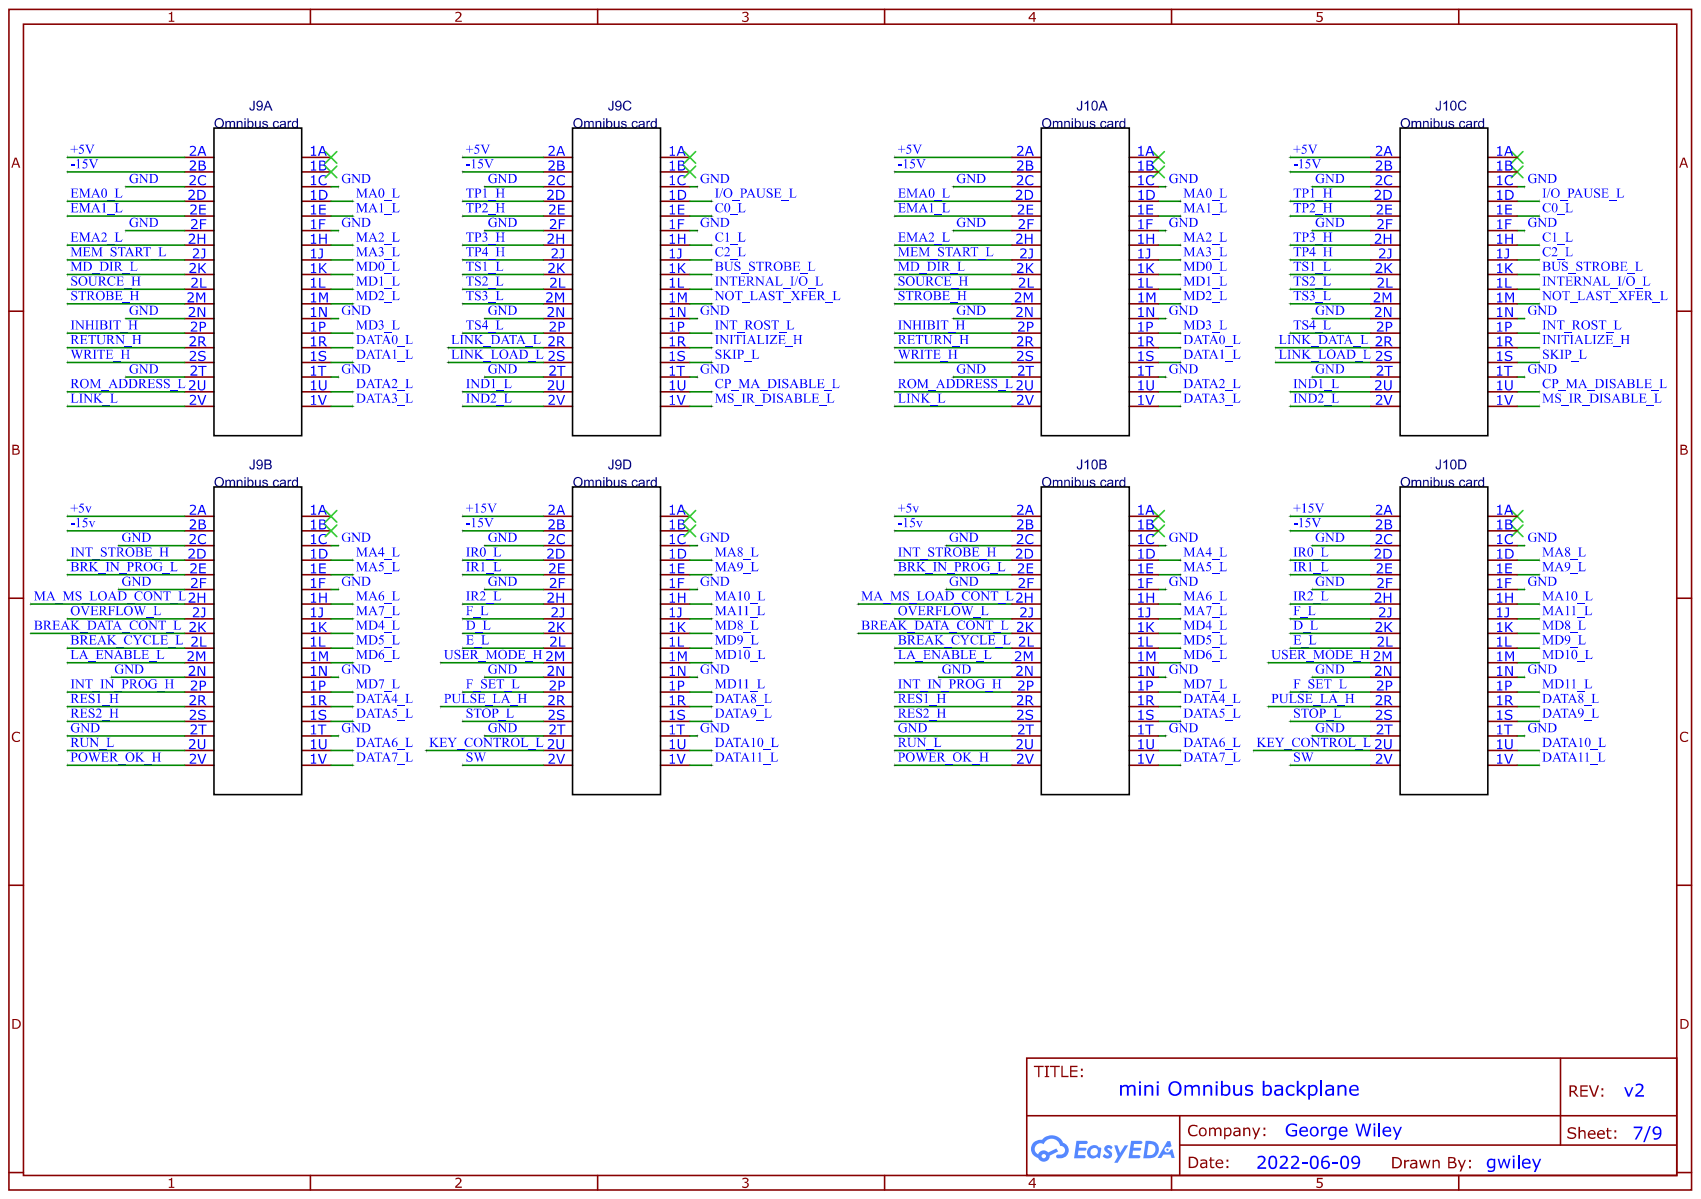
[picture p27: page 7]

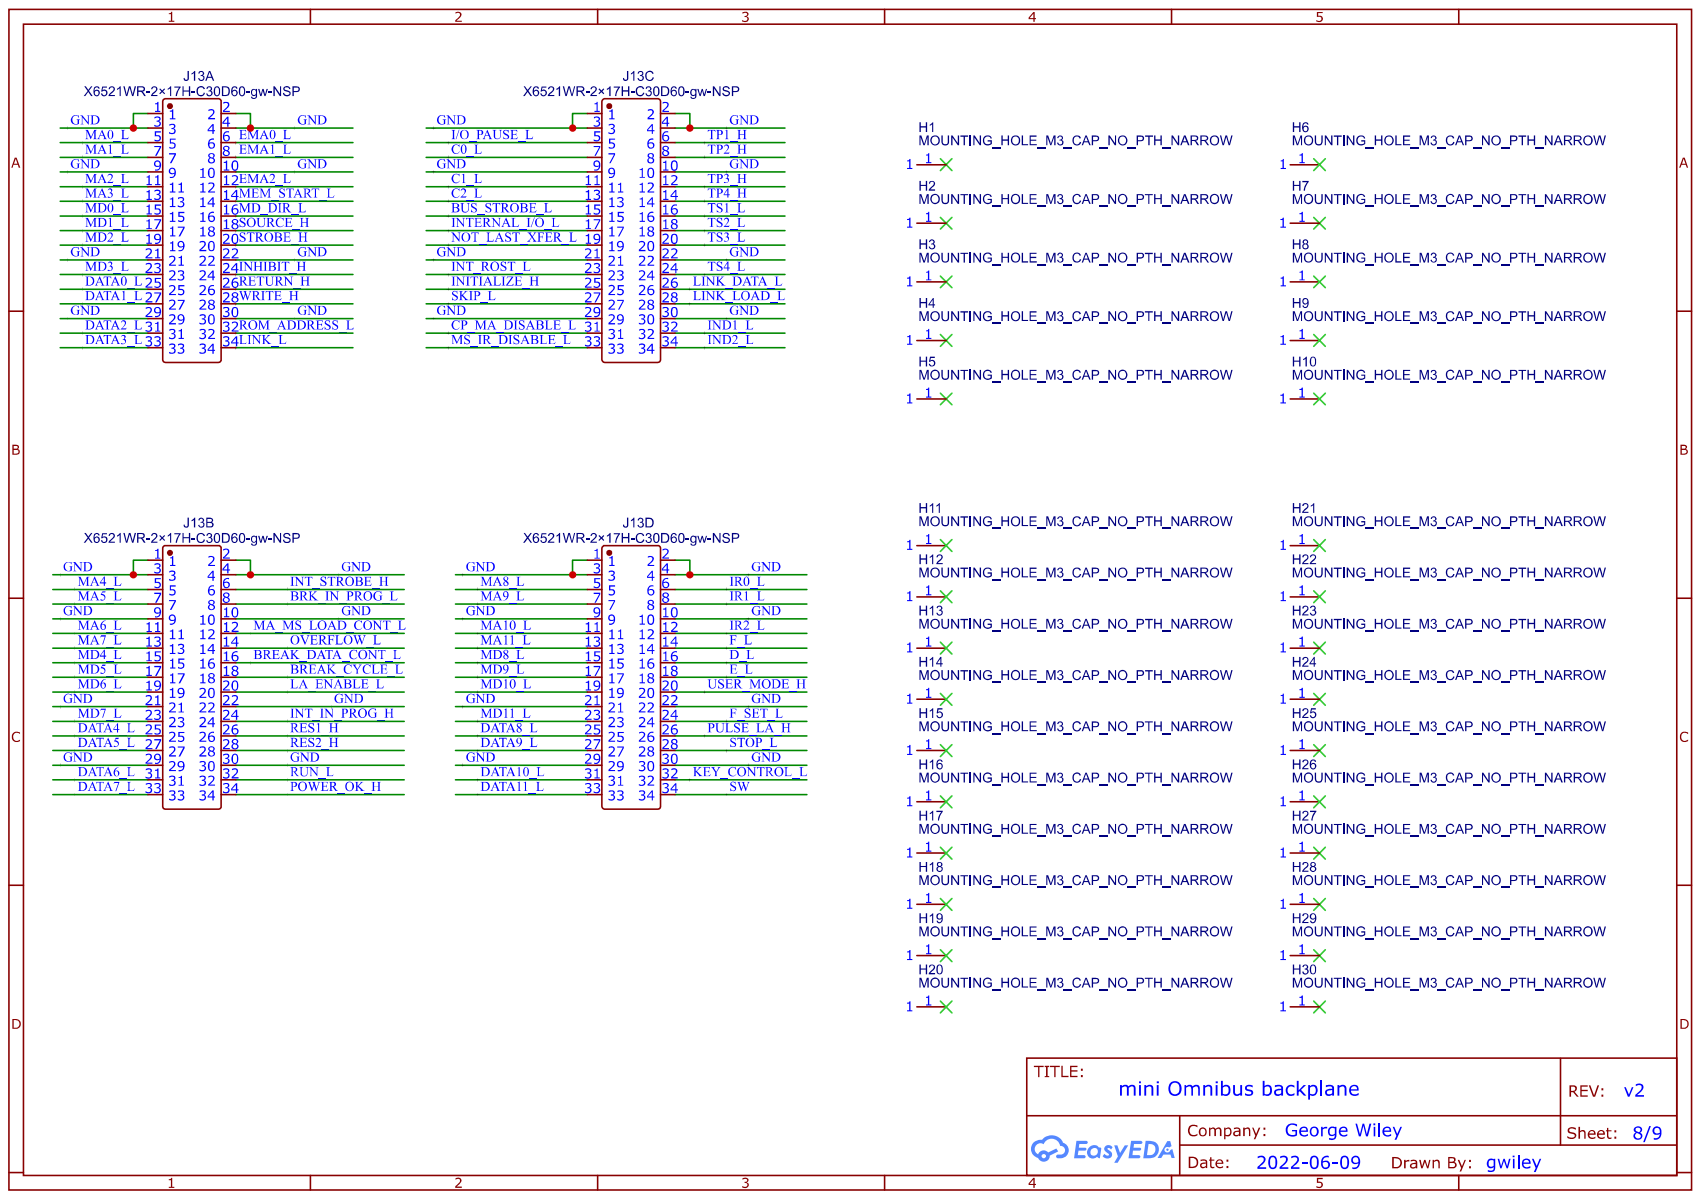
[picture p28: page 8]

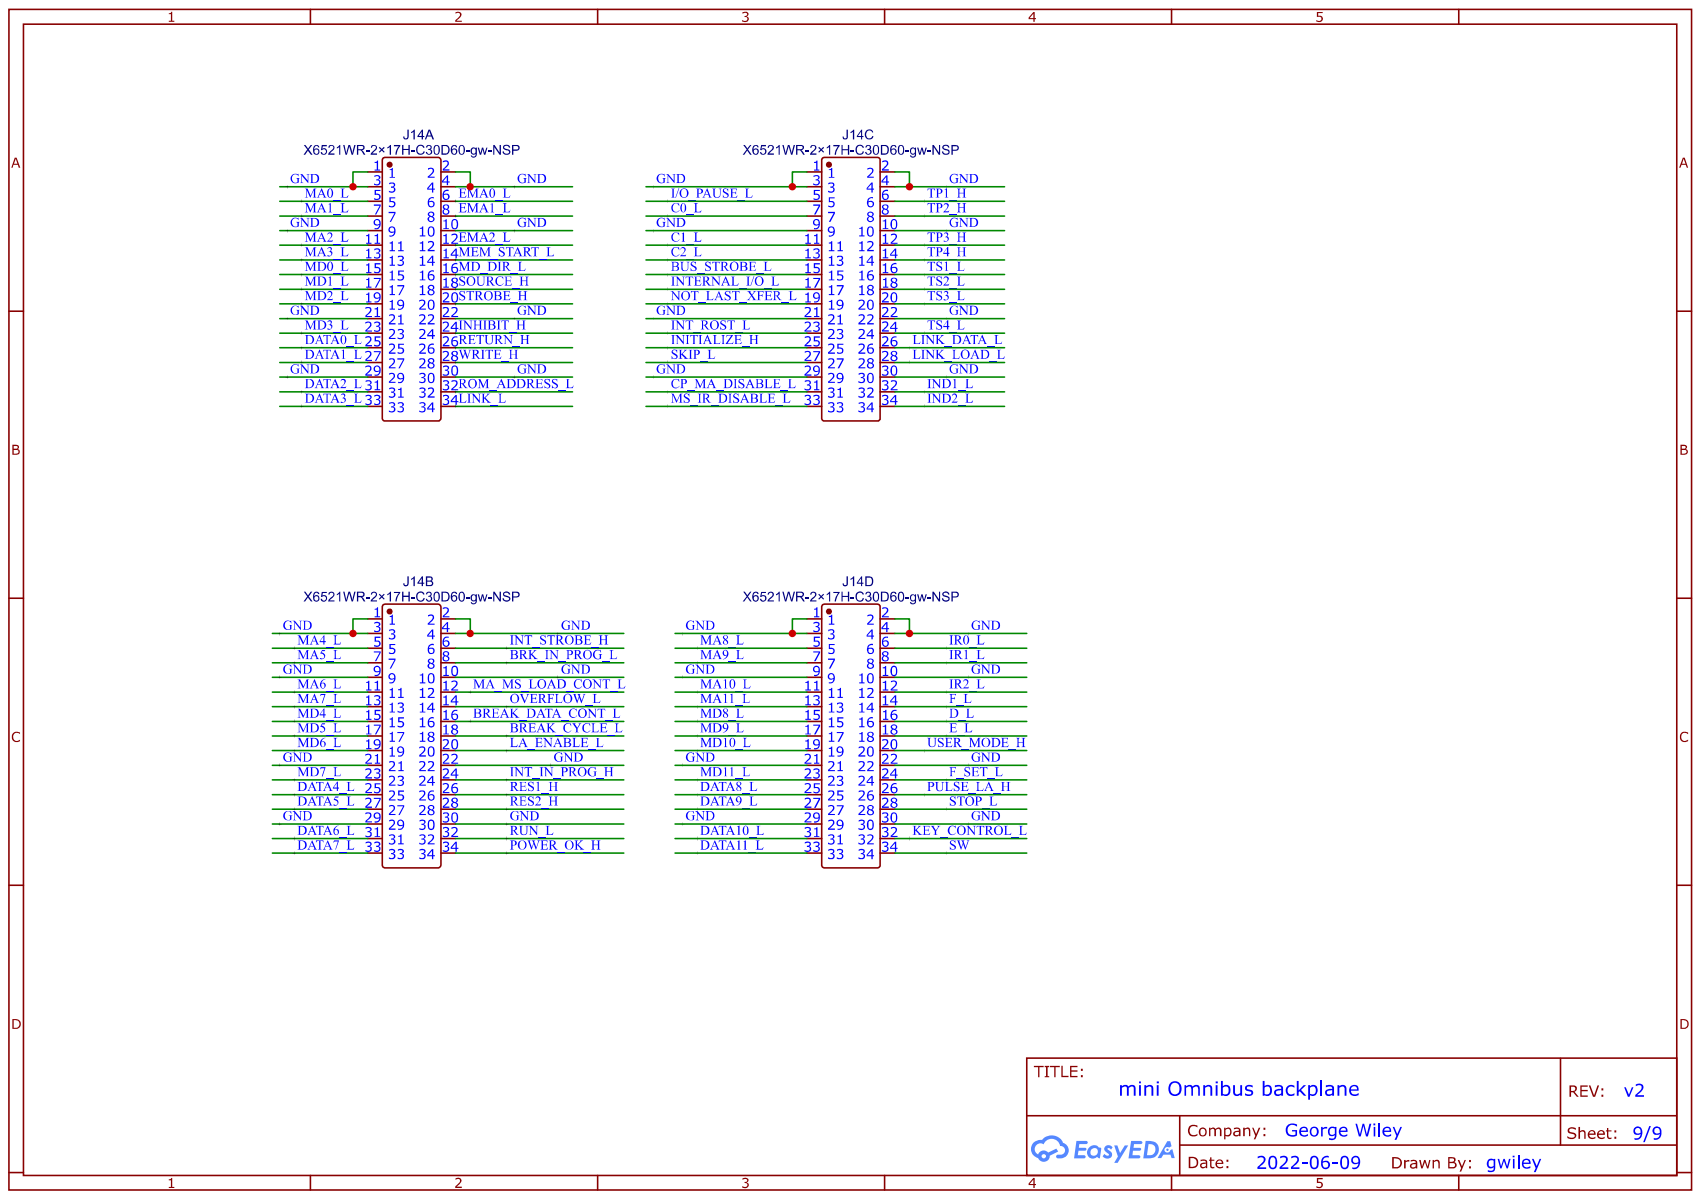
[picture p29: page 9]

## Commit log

2022-06-01 Omnibus_Bridge/
    photo of the Omnibus Bridge board with right-angle header
2022-09-16 Add files via upload
    In case the 3D printing service will not print many parts connected with a network of disposable ribs, this is a smaller grouping of shims that is sufficient for the connectors of one slot in the bac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
    [connector_shim_1_slot_v06.stl]
